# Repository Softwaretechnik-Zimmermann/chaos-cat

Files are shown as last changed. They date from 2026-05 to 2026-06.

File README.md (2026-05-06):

# chaos-cat
Gruppenarbeit Interaktive Systeme - Ein Roboter Haustier das dich durch Chaos aufheitert. Eine Katze die auf deinem Schreibtisch umherfährt und Aufmerksamkeit braucht um ruhig zu bleiben. Wenn es wütend wird schiebt es die Sachen umher uder schiebt diese ganz vom Tisch.
# Visualisierung der Idee
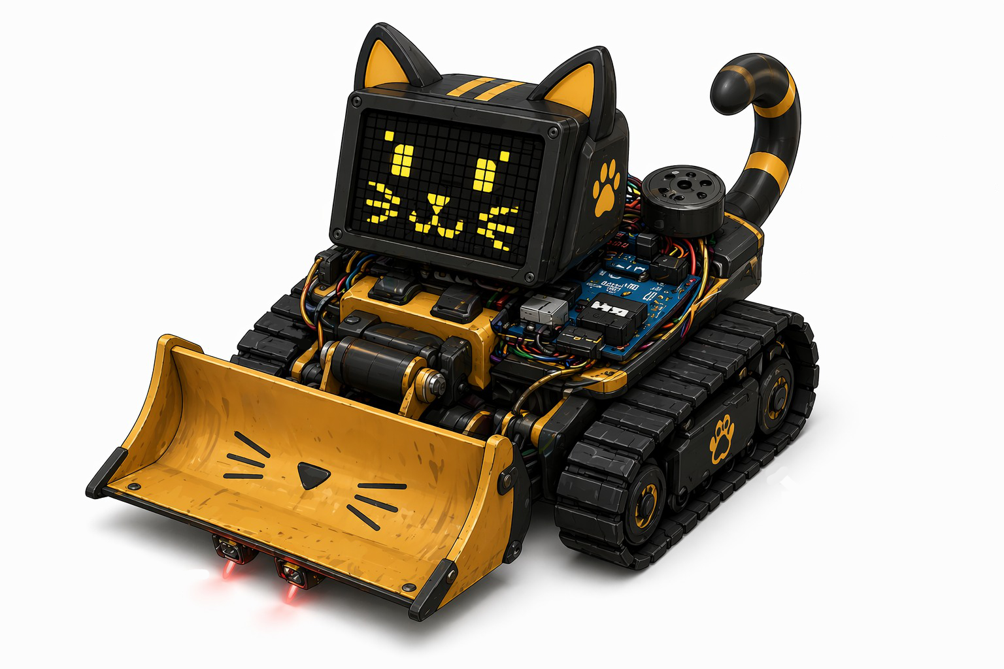
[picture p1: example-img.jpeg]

# IO
Input
* Ultraschall Sensor
* Kapazitiver Sensor

Output
* LED
* Fahrgestell
* Buzzer
* Servo (für Schwanz)

# Gefühlslagen
## Glücklich
Wenn die Chaos-Cat genug Aufmerksamkeit bekommt durch regelmäßiges Streicheln (kapazitiver Sonsor)
* Fährt ruhig herum (Schiebt Gegenstände herum)
* Grüne LED
* Buzzer wie schnurren
* Servomotor beweg sich langsam

## Wütend
Nach einer gewissen Zeit ohne Beachtung (kein Input)
* Schnelles hektisches Fahren (Schmeißt Gegenstände vom Tisch)
* Rote schnell blinkende LED
* Buzzer hektisch hoher Ton
* Servomotor beweg sich hektisch

## Ängstlich
An einer Tischkante wo sich die Chaos-Cat nicht selbst retten kann (Ultraschall Sensor)
* Led Blinkt impulsiv
* Buzzer piebt hektisch
* Bleibt stehen
* Servomotor bleibt stehen
# Ablaufdiagramm
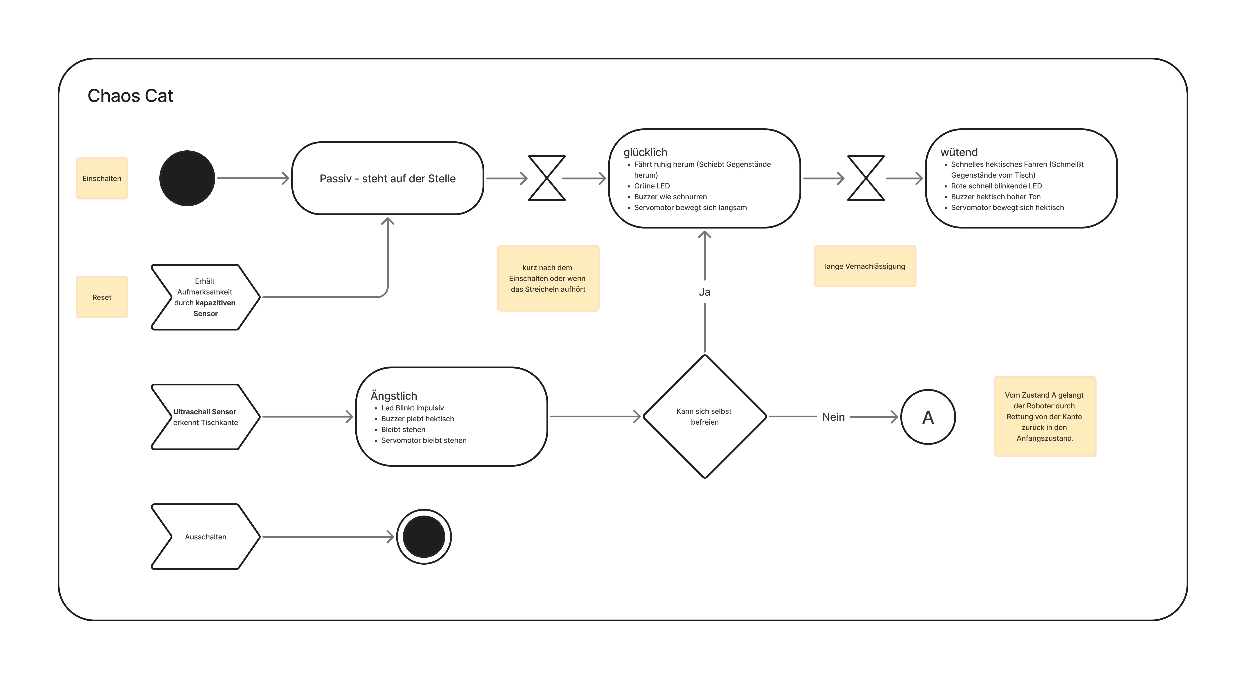
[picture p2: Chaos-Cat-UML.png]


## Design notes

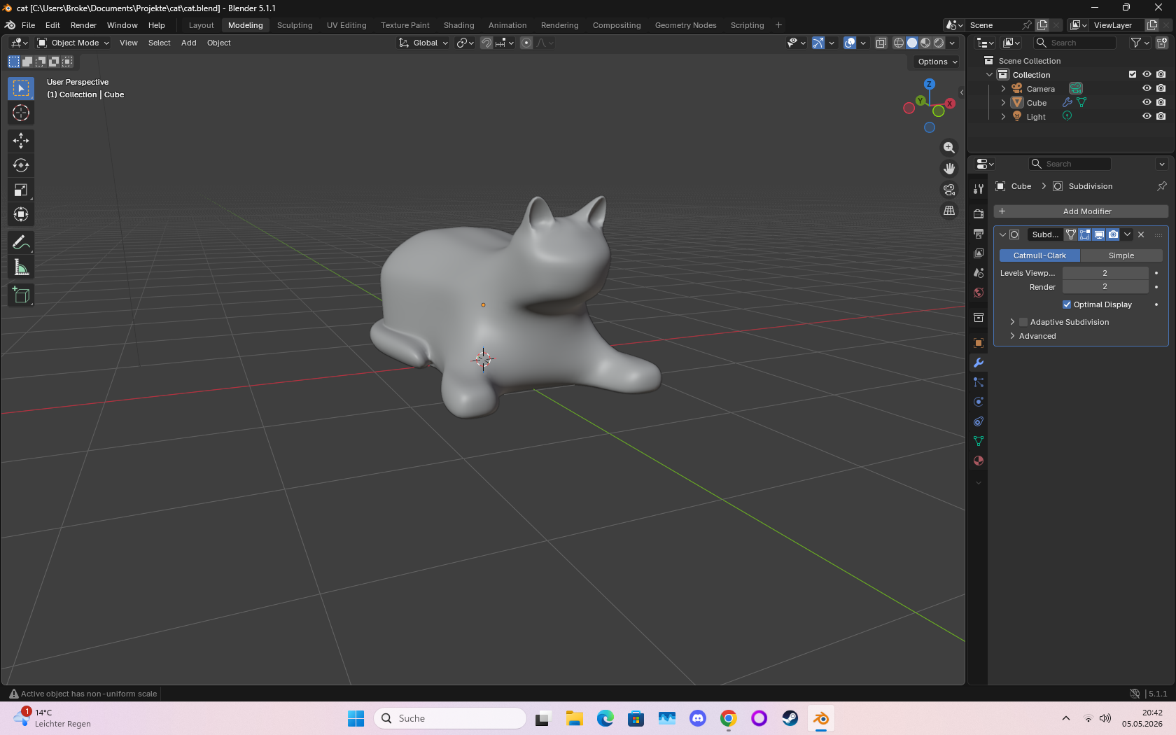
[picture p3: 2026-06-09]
3D-Modell/konzept (Gadse).png

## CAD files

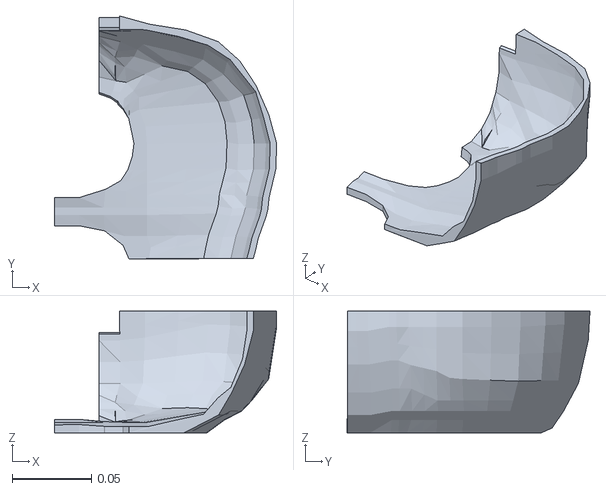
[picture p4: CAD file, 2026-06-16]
3D-Modell/left back (neu und hoffentlich besser).stl
0.14 x 0.153 x 0.0768

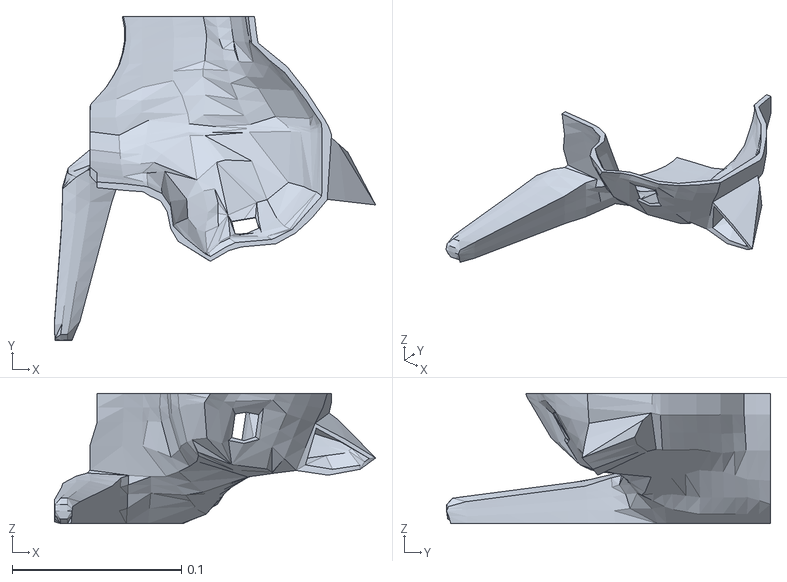
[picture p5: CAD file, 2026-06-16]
3D-Modell/left front (neu und hoffentlich besser).stl
0.19 x 0.191 x 0.0767

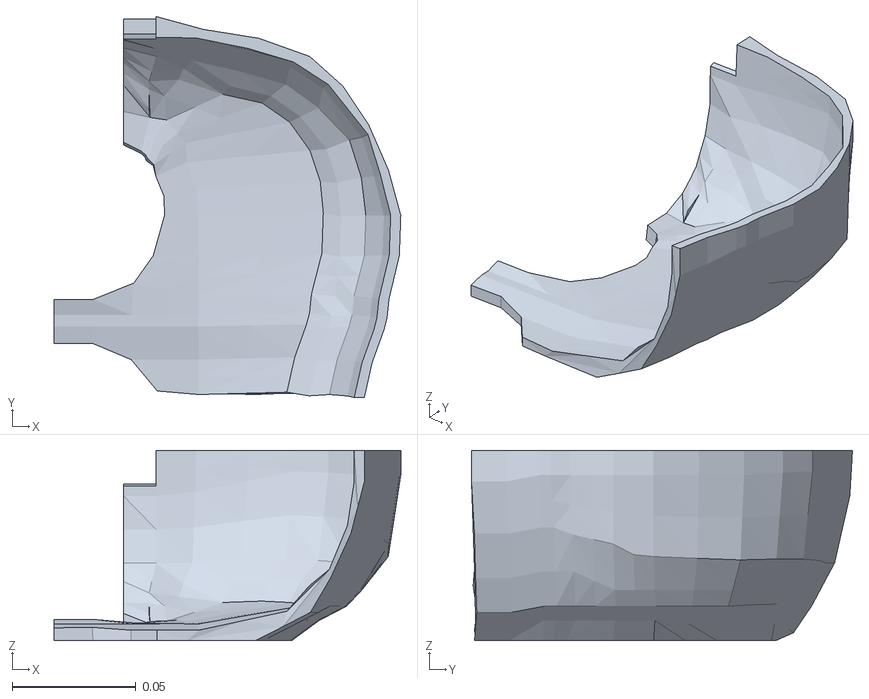
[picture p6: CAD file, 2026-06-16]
3D-Modell/left back.stl
0.14 x 0.154 x 0.0768

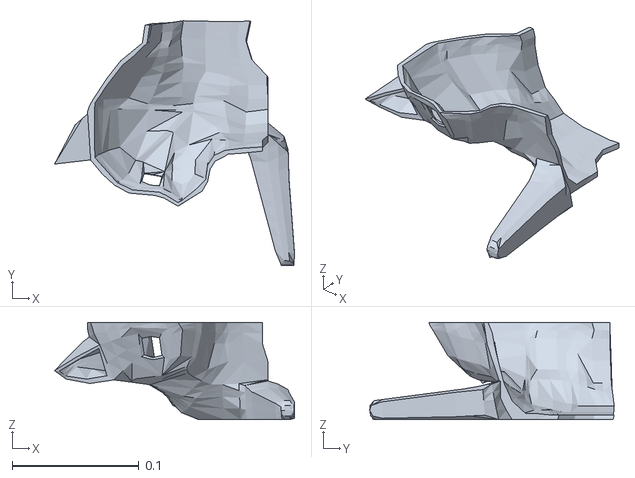
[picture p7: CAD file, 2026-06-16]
3D-Modell/right front.stl
0.19 x 0.193 x 0.0767

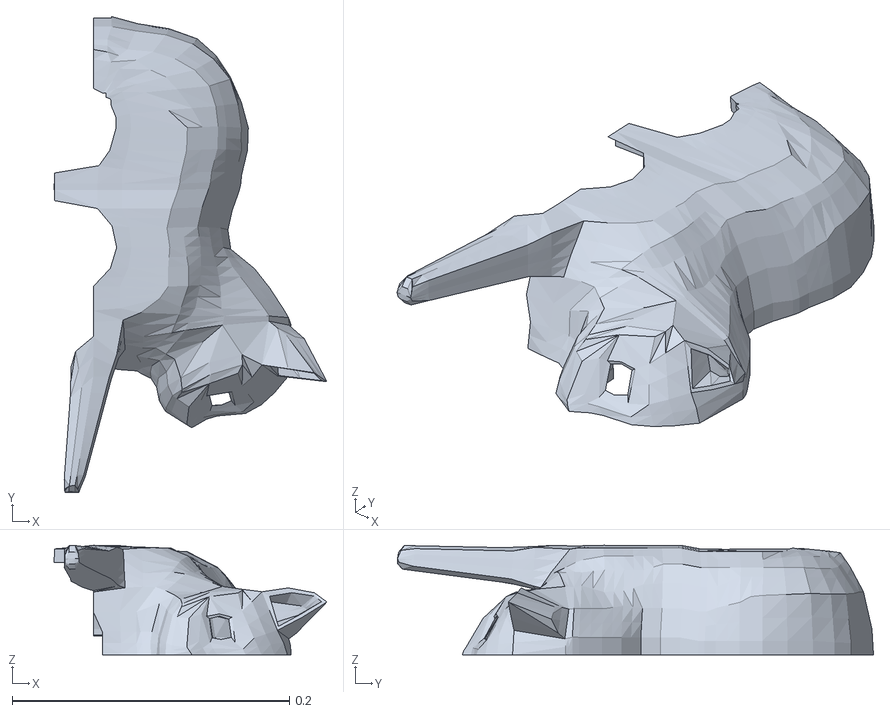
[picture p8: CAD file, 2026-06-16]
3D-Modell/Chassis (right).stl
0.197 x 0.344 x 0.079

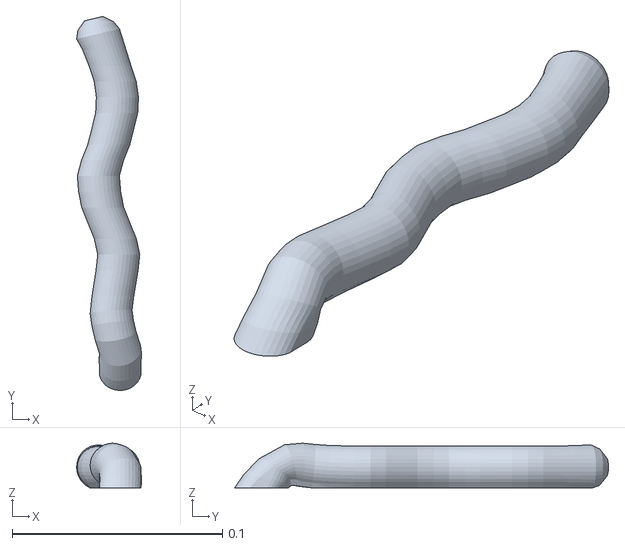
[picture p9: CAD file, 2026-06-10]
3D-Modell/Interaktive Medien (CHAOS-CAT-Tail).stl
0.0308 x 0.178 x 0.0212

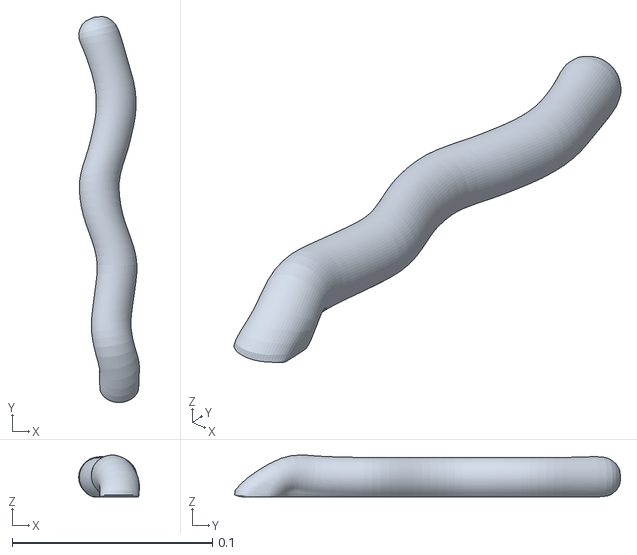
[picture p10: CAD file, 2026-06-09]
3D-Modell/CHAOS-CAT-Tail (Sub-Div).stl
0.0303 x 0.193 x 0.0209

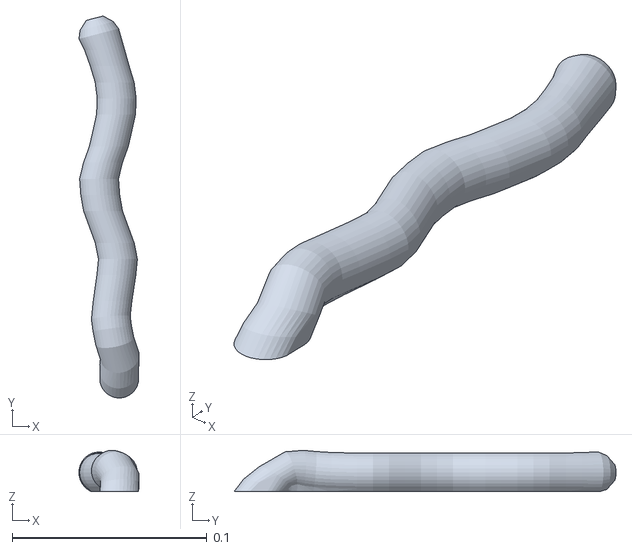
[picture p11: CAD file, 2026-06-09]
3D-Modell/CHAOS-CAT-Tail.stl
0.0309 x 0.196 x 0.0212

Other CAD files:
3D-Modell/right back.stl
3D-Modell/left front.stl
3D-Modell/Chassis (left).stl
3D-Modell/Chassis (left).blend
3D-Modell/Chassis (right).blend
3D-Modell/Interaktive Medien (CHAOS-CAT).blend
3D-Modell/Interaktive Medien (CHAOS-CAT+Chassis 90 grad).blend
3D-Modell/Interaktive Medien (CHAOS-CAT-Tail).blend
3D-Modell/catata split.blend
3D-Modell/konzept (cat).blend
3D-Modell/left back.blend
3D-Modell/left front.blend
3D-Modell/right back.blend
3D-Modell/right front.blend

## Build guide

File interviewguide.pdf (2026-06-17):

Chaos Cat - Interview Guide | Page 1

# Interview Guide - Chaos Cat

Open-ended interview guide for evaluating the usability and understandability of the interactive system.

System | Chaos Cat - an interactive robotic cat that communicates through movement, LED colors, sound, touch input, ultrasonic sensing, and tail movement.
Goal | Understand how participants interpret the cat's behavior, emotional modes, feedback signals, and interaction flow.
Duration | Approx. 10-15 minutes after a short interaction with the prototype.

## Interview Setup

1 Ask the participant to interact freely with Chaos Cat first.
2 Avoid explaining the modes before the main questions, so their first interpretation is not influenced.
3 Use follow-up prompts such as: "Can you tell me more?", "What made you think that?", and "How did that feel?"

## Warm-up Questions

1 Can you tell us about your previous experience with robots,
interactive toys, or playful technical systems?

Probe for familiar systems, expectations, and confidence with technology.

### 2 When you use an unfamiliar device, how do you usually figure out

what it is doing or what it expects from you?

Probe for preferred clues: sound, movement, lights, labels, trial and error.

### 3 What kind of behavior would you expect from a small interactive

robotic cat?

Probe for emotional reactions, movement, safety, and personality expectations.

## Main Questions

### 1 Looking at Chaos Cat for the first time, what do you think its

purpose is and how would you describe it?

Probe for first impression and whether the concept is recognizable.

### 2 During the interaction, how did you understand which mode or

emotional state the cat was in?

Probe for Passive, Happy, Angry, and Afraid mode recognition.

### 3 Which feedback signals were easiest or hardest to interpret:

movement, LED color, sound, tail movement, or direction changes?

Probe for clarity, timing, and possible conflicting signals.

### 4 How natural or clear was the interaction through touching the

copper foil?

Probe for whether the touch input felt discoverable and responsive.

### 5 How did the transition from Passive to Happy and then to Angry

feel to you?

Probe for whether the timing felt too fast, too slow, surprising, or understandable.

### 6 What did you expect Chaos Cat to do when it reached the table

edge or entered Afraid mode?

Probe for safety, trust, and whether the backwards movement made sense.

### 7 Which parts of the behavior felt enjoyable, surprising, annoying, or

unclear?

Probe for emotional response and usability problems.

### 8 If someone had to use Chaos Cat without an explanation, what

would help them understand it faster?

Probe for possible improvements in feedback, onboarding, or physical design.

## Closing Questions

### 1 What would you change or improve to make Chaos Cat easier or

more enjoyable to interact with?

Probe for concrete design improvements.

2 | Is there anything else you noticed that we did not ask about? | Give the participant space for final thoughts.

Note for interviewer: Keep the conversation open and neutral. Ask follow-up questions when participants mention confusion, surprise, or expectations about the system.

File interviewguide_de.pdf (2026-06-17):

Chaos Cat - Interviewleitfaden | Seite 1

# Interviewleitfaden - Chaos Cat

Offener Interviewleitfaden zur Evaluation der Nutzbarkeit und Verständlichkeit des interaktiven Systems.

System | Chaos Cat - eine interaktive Roboterkatze, die über Bewegung, LED-Farben, Töne, Berührung, Ultraschallsensorik und Schwanzbewegung kommuniziert.
Ziel | Verstehen, wie Teilnehmende das Verhalten der Katze, die emotionalen Modi, die Feedback-Signale und den Interaktionsablauf interpretieren.
Dauer | Ca. 10-15 Minuten nach einer kurzen Interaktion mit dem Prototyp.

## Interview-Ablauf

1 Die teilnehmende Person zuerst frei mit Chaos Cat interagieren lassen.

2 Die Modi vor den Hauptfragen nicht erklären, damit die erste Interpretation nicht beeinflusst wird.

3 Mögliche Nachfragen: "Können Sie das genauer beschreiben?", "Woran haben Sie das erkannt?" und "Wie hat sich das angefühlt?"

## Warm-up-Fragen

### 1 Welche Erfahrungen haben Sie bisher mit Robotern, interaktiven

Spielzeugen oder spielerischen technischen Systemen gemacht?

Nach bekannten Systemen, Erwartungen und Sicherheit im Umgang mit Technik fragen.

### 2 Wenn Sie ein unbekanntes Gerät benutzen, wie finden Sie

normalerweise heraus, was es macht oder was es von Ihnen erwartet?

Nach bevorzugten Hinweisen fragen: Ton, Bewegung, Licht, Beschriftung, Ausprobieren.

### 3 Welches Verhalten würden Sie von einer kleinen interaktiven

Roboterkatze erwarten?

Nach emotionalen Reaktionen, Bewegung, Sicherheit und Persönlichkeit fragen.

## Hauptfragen

### 1 Wenn Sie Chaos Cat zum ersten Mal sehen, was denken Sie, wofür

das System gedacht ist, und wie würden Sie es beschreiben?

Nach erstem Eindruck und Verständlichkeit des Konzepts fragen.

### 2 Wie haben Sie während der Interaktion erkannt, in welchem Modus

oder emotionalen Zustand sich die Katze befindet?

Nach Erkennung von Passiv-, Happy-, Angry-und Angstmodus fragen.

### 3 Welche Feedback-Signale waren am leichtesten oder schwersten zu

interpretieren: Bewegung, LED-Farbe, Ton, Schwanzbewegung oder Richtungswechsel?

Nach Klarheit, Timing und möglichen widersprüchlichen Signalen fragen.

### 4 Wie natürlich oder verständlich war die Interaktion über das Berühren

der Kupferfolie?

Nach Auffindbarkeit und
Reaktionsgeschwindigkeit der Touch-Eingabe fragen.

### 5 Wie hat sich der Übergang von Passiv zu Happy und danach zu

Angry für Sie angefühlt?

Nach Timing fragen: zu schnell, zu langsam, überraschend oder nachvollziehbar.

### 6 Was haben Sie erwartet, als Chaos Cat an die Tischkante kam oder in

den Angstmodus gewechselt ist?

Nach Sicherheit, Vertrauen und Verständlichkeit der Rückwärtsbewegung fragen.

7 Welche Teile des Verhaltens wirkten angenehm, überraschend, störend oder unklar?

Nach emotionaler Wirkung und möglichen Usability-Problemen fragen.

### 8 Wenn jemand Chaos Cat ohne Erklärung benutzen müsste, was

würde helfen, das System schneller zu verstehen?

Nach Verbesserungen bei Feedback, Einstieg und physischem Design fragen.

## Abschlussfragen

### 1 Was würden Sie ändern oder verbessern, damit Chaos Cat einfacher

oder angenehmer zu benutzen ist?

Nach konkreten Verbesserungsvorschlägen fragen.

### 2 Gibt es noch etwas, das Ihnen aufgefallen ist und wonach wir nicht

gefragt haben?

Raum für letzte Gedanken und zusätzliche Beobachtungen geben.

Hinweis für die Interviewleitung: Das Gespräch offen und neutral führen. Bei Verwirrung, Überraschung oder Erwartungen der Teilnehmenden gezielt nachfragen.

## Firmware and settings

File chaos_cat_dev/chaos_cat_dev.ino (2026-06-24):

#include <Servo.h>

const int SERVO_MIN_PULSE = 420;
const int SERVO_MAX_PULSE = 2420;

const uint8_t SEND_PIN = 4; // Resistor
const uint8_t RECIEVE_PIN = 5; // copper foil to touch

const uint8_t PIN_LED_R = 6;
const uint8_t PIN_LED_G = 7;
const uint8_t PIN_LED_B = 10;

const uint8_t PWMA_MOTOR = 3;
const uint8_t BREAKER_B_MOTOR = 8;
const uint8_t BREAKER_A_MOTOR = 9;
const uint8_t PWMB_MOTOR = 11;
const uint8_t DIRA_MOTOR = 12;
const uint8_t DIRB_MOTOR = 13;

const uint8_t TRIG_PIN = A0; 
const uint8_t ECHO_PIN = A1; 

const uint8_t BUZZER_PIN = A2;

const uint8_t SERVO_PIN = A3;

Servo tailServo;

void setup() {
  tailServo.attach(SERVO_PIN, SERVO_MIN_PULSE, SERVO_MAX_PULSE);
  Serial.begin(9600);  
  Serial.println("Ultrasonic sensor:");

  pinMode(SEND_PIN, OUTPUT);

  pinMode(PIN_LED_R, OUTPUT);
  pinMode(PIN_LED_G, OUTPUT);
  pinMode(PIN_LED_B, OUTPUT);

  pinMode(BREAKER_B_MOTOR,OUTPUT);  
  pinMode(BREAKER_A_MOTOR,OUTPUT);  
  pinMode(DIRA_MOTOR,OUTPUT);  
  pinMode(DIRB_MOTOR,OUTPUT);  

  pinMode(TRIG_PIN, OUTPUT);
  pinMode(ECHO_PIN, INPUT);

  pinMode(BUZZER_PIN, OUTPUT);
}

enum State {
  PASSIVE,
  HAPPY,
  ANGRY,
  AFRAID
};

State currentState = State::PASSIVE; // Set the initial state
State preState = State::PASSIVE; // Set the previous state

int timer = 0;
long time = 0;
float servoTimer = 1;

int passiveToHappyWait = 5; // in Seconds
int happyToAngryWait = 20;

const int servoMinAngle = 0;
const int servoMaxAngle = 30;
bool servoFwd = true;

unsigned long lastSound = 0;
unsigned long happyTime = 0;
bool secondTone = false;


void loop() {
  resetState();

  switch(currentState) {
    case State::PASSIVE:
      setPassiveState();
      break;
    case State::HAPPY:
      setHappyState();
      break;
    case State::ANGRY:
      setAngryState();
      break;
    case State::AFRAID:
      setAfraidState();
      break;
  }

  timer ++;
  time ++;
  updateBuzzer();

  int loopDelay = 10;
  delay(loopDelay);
  if(currentState == State::PASSIVE && timer > passiveToHappyWait * 1000 / loopDelay || currentState == State::HAPPY && timer > happyToAngryWait * 1000 / loopDelay){
    timer = 0;
    nextState();
  }

  if(servoTimer > servoMaxAngle || servoTimer < 1){
    servoFwd = !servoFwd;
  }

  setServo(servoTimer);

  if (time % 2 == 1){ 
    readTouch();
  } else {
    readUltrasonic();
  }
}

// Input - capacitive Sensor
void readTouch(){
  long touchTime = 0;
  pinMode(RECIEVE_PIN, OUTPUT);
  digitalWrite(RECIEVE_PIN, LOW); 
  digitalWrite(SEND_PIN, LOW); 
  delayMicroseconds(10);
  pinMode(RECIEVE_PIN, INPUT);

  digitalWrite(SEND_PIN, HIGH); 
  while(digitalRead(RECIEVE_PIN) == LOW){
    touchTime++;
  }
  digitalWrite(SEND_PIN, LOW); 
  if(touchTime > 10){ 
    currentState = State::PASSIVE;
    timer = 0;
  }
}

// Input - ultrasonic Sensor
void readUltrasonic(){
  if (currentState == State::AFRAID) return;

  unsigned long distance = readDistance();

  if(distance > 10){ // ende der Tischkante = großer Abstand zum Sensor
    if (currentState != State::AFRAID)
      preState = currentState;
    currentState = State::AFRAID;
  }
}

unsigned long readDistanceAverage() {
  unsigned long sum = 0;
  for (int i = 0; i < 4; i++) sum += readDistance();
  return sum / 4;
}

unsigned long readDistance() {
  digitalWrite(TRIG_PIN, LOW);
  delayMicroseconds(2);
  digitalWrite(TRIG_PIN, HIGH);
  delayMicroseconds(10);
  digitalWrite(TRIG_PIN, LOW);

  unsigned long duration = pulseIn(ECHO_PIN, HIGH, 20000); 
  int distance = duration * 0.034 / 2; // Umrechnung in cm

  Serial.println(distance);
  return distance;
}

// Output - Servo
void setServo(int pos) {
  tailServo.write(pos);
}

// Output - Buzzer
void updateBuzzer(){

  switch(currentState){
    case PASSIVE:
      if(millis()-lastSound>7000){
        lastSound=millis();
        tone(BUZZER_PIN,700,150);
      }
      break;

    case HAPPY:
      if(!secondTone && millis()-lastSound>3000){
        lastSound=millis();
        tone(BUZZER_PIN,900,100);
        happyTime=millis();
        secondTone=true;
      }
      if(secondTone && millis()-happyTime>120){
        tone(BUZZER_PIN,1200,100);
        secondTone=false;
      }
      break;

    case ANGRY:
      if(millis()-lastSound>800){
        lastSound=millis();
        tone(BUZZER_PIN,300,150);
      }
      break;
  }
}

// Output - Motor
void driveForward(int speed){ // TODO Überarbeiten
  if(currentState == State::HAPPY){
    if (time % 1000 > 1 && time % 1000 < 400){ 
      driveRight(speed);
    } else if (time % 1000 > 600 && time % 1000 < 900){
      driveLeft(speed);
    } else {
    drive(true, true, speed, speed);
    }
  }
  if(currentState == State::ANGRY){
    if (time % 100 > 1 && time % 100 < 30){ 
      driveRight(speed);
    } else if (time % 100 > 60 && time % 100 < 90){
      driveLeft(speed);
    } else {
    drive(true, true, speed, speed);
    }
  }
}

void driveBackward(int speed){
  drive(false, false, speed, speed);
}

void driveLeft(int speed){
  drive(true, true, 0, speed);
}

void driveRight(int speed){
  drive(true, true, speed, 0);
}

void drive(bool leftFWD, bool rightFWD, int speedL, int speedR){ // FWD = False means backwards, speed range from 0 to 255
  if (leftFWD){
    digitalWrite(DIRA_MOTOR, HIGH); // forward direction A
  } else {    
    digitalWrite(DIRA_MOTOR, LOW); // backward direction A
  }
  digitalWrite(BREAKER_A_MOTOR, LOW); // Brake A off
  analogWrite(PWMA_MOTOR, speedL); // Spins the motor A 
  if (rightFWD){
    digitalWrite(DIRB_MOTOR, HIGH); // forward direction B
  } else {    
    digitalWrite(DIRB_MOTOR, LOW); // backward direction B
  }
  digitalWrite(BREAKER_B_MOTOR, LOW); // Brake B off
  analogWrite(PWMB_MOTOR, speedR); // Spins the motor B
}


// State Logic
void nextState() {
  if (currentState == State::PASSIVE) currentState = State::HAPPY; 
  else if (currentState == State::HAPPY) currentState = State::ANGRY; 
}

void resetState(){
  // Reset LEDs
  digitalWrite(PIN_LED_R, LOW);
  digitalWrite(PIN_LED_G, LOW);
  digitalWrite(PIN_LED_B, LOW);
}

void setPassiveState(){
  if(servoFwd){
    servoTimer += 0.2;
  }
  else{
    servoTimer -= 0.2;
  }
  digitalWrite(BREAKER_A_MOTOR, HIGH); // Brake A on
  digitalWrite(BREAKER_B_MOTOR, HIGH); // Brake B on
  // White LEDs
  digitalWrite(PIN_LED_R, HIGH);
  digitalWrite(PIN_LED_G, HIGH);
  digitalWrite(PIN_LED_B, HIGH);
}

void setHappyState(){
  if(servoFwd){
    servoTimer += 0.5;
  }
  else{
    servoTimer -= 0.5;
  }
  driveForward(255);
  digitalWrite(PIN_LED_G, HIGH); // Green LEDs
}

void setAngryState(){
    if(servoFwd){
    servoTimer += 0.8;
  }
  else{
    servoTimer -= 0.8;
  }
  driveForward(255);
  digitalWrite(PIN_LED_R, HIGH); // Red LEDs
}

void setAfraidState(){
  digitalWrite(PIN_LED_B, HIGH); // Blue LEDs
  digitalWrite(BREAKER_A_MOTOR, HIGH); // Brake A on
  digitalWrite(BREAKER_B_MOTOR, HIGH); // Brake B on
  //delay(500);
  // try driving backwards
  driveBackward(255);
  // SOS
  int SOSDelay = 200;
  int shortDel = SOSDelay -100;
  tone(BUZZER_PIN,1200,shortDel); delay(SOSDelay);
  tone(BUZZER_PIN,1200,shortDel); delay(SOSDelay);
  tone(BUZZER_PIN,1200,shortDel); delay(SOSDelay);

  tone(BUZZER_PIN,1200,2*SOSDelay-100); delay(2*SOSDelay);
  tone(BUZZER_PIN,1200,2*SOSDelay-100); delay(2*SOSDelay);
  tone(BUZZER_PIN,1200,2*SOSDelay-100); delay(2*SOSDelay);

  tone(BUZZER_PIN,1200,shortDel); delay(SOSDelay);
  tone(BUZZER_PIN,1200,shortDel); delay(SOSDelay);
  tone(BUZZER_PIN,1200,shortDel); delay(SOSDelay);

    unsigned long distance = readDistance();

  if(distance > 10){
    currentState = State::AFRAID;
  }
  else{
    currentState = preState;
  }
}

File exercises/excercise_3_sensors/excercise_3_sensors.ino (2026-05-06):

const uint8_t PIN_LED_B = 8;
const uint8_t PIN_LED_G = 10;
const uint8_t PIN_LED_R = 12;
const uint8_t EchoPin = 5;
const uint8_t TrigPin = 4;

void setup() {
  // put your setup code here, to run once:
  Serial.begin(9600);  

  pinMode(PIN_LED_R, OUTPUT);
  pinMode(PIN_LED_G, OUTPUT);
  pinMode(PIN_LED_B, OUTPUT);
  pinMode(EchoPin, INPUT);               // Set echo pin as input
  pinMode(TrigPin, OUTPUT);

  Serial.println("Ultrasonic sensor:");
}

void loop() {
  unsigned long distance = readDistance();  // Call the function to read the sensor data and get the distance
  Serial.println(distance);           // Print the distance value
  //Serial.println(" microsec");            // Print " cm" to indicate the unit of measurement
  //delay(400);                       // Delay for 400 milliseconds before repeating the loop
}

// Function to read the sensor data and calculate the distance
unsigned long readDistance() {
  digitalWrite(TrigPin, LOW);   // Set trig pin to low to ensure a clean pulse
  delayMicroseconds(2);         // Delay for 2 microseconds
  digitalWrite(TrigPin, HIGH);  // Send a 10 microsecond pulse by setting trig pin to high
  delayMicroseconds(10);
  digitalWrite(TrigPin, LOW);  // Set trig pin back to low

  // Measure the pulse width of the echo pin and calculate the distance value
  unsigned long distance = pulseIn(EchoPin, HIGH); 
  return distance;
}

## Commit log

2026-05-06 Revise README to focus on visualization and flowchart
    Removed implementation details and added flowchart.
2026-05-11 added servo with speed like mood
2026-05-19 Add servo control and state management for chaos cat
2026-05-27 merged ultrasonic code from Onor
2026-06-09 Weil ich die in nen Ordner haben wollte
    [konzept (cat).blend]
2026-06-10 updated tail
    [Interaktive Medien (CHAOS-CAT-Tail).blend, Interaktive Medien (CHAOS-CAT-Tail).stl]
2026-06-10 fixed servo stuck
2026-06-14 Servor more fluent
2026-06-15 servo speed changed
2026-06-16 Ich hoffe die hauen für das drucken hin
    Vor dem Drucken bitte Modell nochmal anschauen/bearbeiten in Blender (mir Bescheid geben)
    [Chassis (left).blend, Chassis (left).stl, Chassis (right).blend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]
2026-06-16 3D-Modell (gesplitet)
    Modell in 4 Teile geteilt um den Druck zu erleichtern (von Mattis an Steens Laptop)
    [Chassis (left).blend, Interaktive Medien (CHAOS-CAT+Chassis 90 grad).blend, catata split.blend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]
2026-06-16 Verbessert (mit jetzt hoffentlich genügend platz für Räder)
    [left back (neu und hoffentlich besser).stl, left back.blend, left front (neu und hoffentlich besser).stl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]
2026-06-24 sensor check in end of angry mode
